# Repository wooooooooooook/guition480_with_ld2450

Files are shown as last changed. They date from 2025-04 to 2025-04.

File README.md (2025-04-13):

# guition480_with_ld2450
guition 4'' display ESP32-S3-4848S040 with LD2450 sensor

### 재료
- guition 4'' display ESP32-S3-4848S040 (3 relay 모델 기준 https://ko.aliexpress.com/item/1005006335587633.html) 
- LD2450 sensor (https://ko.aliexpress.com/item/1005007198006311.html)
- MX 1.25 4pin cable (https://ko.aliexpress.com/item/1005007277110532.html) : guition display에 연결
- ZH 1.5 4pin cable (https://ko.aliexpress.com/item/1005007277030322.html) : LD2450에 연결
- M4 둥근머리 볼트 25mm (더 길어도 관계없음. 스위치 고정에 쓰이는 볼트(이도피스) 재활용가능)
- [3D 프린팅 파츠](https://github.com/wooooooooooook/guition480_with_ld2450/tree/main/printing%20parts)

### 하드웨어


우측 상단에 1.25mm 4pin UART 포트가 존재함.
백패널과 연결포트에도 UART포트가 들어가는데 우측상단의 UART와 UART0핀을 공유하고있음 (GPIO 44, 43) 
백패널로 가는 uart는 저항이 없고, uart포트는 100옴 저항이 달려있음. 



100옴 저함 2개를 인두기로 제거후 납을묻혀 연결시켜야함.



백패널의 Rx, Tx는 아무데도 연결되지 않은것으로보임.
따라서 4pin UART포트를 사용 가능함.



포트 노출을 위해 뒷판을 잘라내야함. (사진 보다 깊게 잘라야 간섭이 없음)

### 어댑터 3D 프린터 출력


[프린팅파츠](https://github.com/wooooooooooook/guition480_with_ld2450/tree/main/printing%20parts)
프린팅 파츠에서 `cover.stl`, `plate.stl`을 출력.
- `plate_v2.stl`은 디스플레이 제거를 쉽게하기위해 하단 지지대를 뚫어놓은 버전입니다. 필요시 이 버전으로 사용하세요. 실제 출력 테스트는 안해봤습니다.

### ESPHome 펌웨어 설치
벽면에 설치후에는 usb포트노출이 안되므로 최초 1회는 USB-C 연결해서 유선으로 펌웨어설치가 필요함.
이후에는 OTA로 업데이트가능. 
[configuration.yaml](https://github.com/wooooooooooook/guition480_with_ld2450/blob/main/esphome%20configuration/guition.yaml)
YAML을 참조하여 ESPHome 펌웨어 설치.

### 설치하기


벽면에 사진과 같이 plate에 LD2450를 장착하고(그냥 걸쳐져있는 방식) 케이블을 잘 정리해서 볼트로 고정시킨다.
케이블의 경우 MX1.25와 ZH1.5케이블을 5V->5V, Rx->Tx, Tx->Rx, Gnd->Gnd가 되도록 연결했음. 



주의해서 L, N, L1~3을 연결하고 LD2450케이블은 위쪽으로 위치시켜서 디스플레이를 장착한다.



M4 볼트로 고정된 모습. (3D 프린팅에 나사를 밀어넣는 방식이므로 너무 세게 조이면 안됩니다.)



LD2450케이블을 본체에 연결한뒤 결합하면 완성





### 철거하기
- 커버 아래의 1자 틈에 1자드라이버를 넣고 비틀어 커버를 분리.
- 디스플레이의 좌우를 잡고 잘 뜯기.. ( 하단의 고정 홈을 누를 도구가 있다면 누르면서 뽑기)
- 이후 보이는 볼트를 제거하면서 탈거할 수 있음.

### 펌웨어 기본 기능
- Light 1~3은 후면 L1~3의 릴레이를 작동시킴
- Switch 1~3은 HA에서 자동화를통해 연동시켜 사용
- LD2450을 활용해 접근시 (2m이내) 화면이 켜짐. (딜레이가 있어 답답할 수도 있습니다)
- [Guition](https://devices.esphome.io/devices/Guition-ESP32-S3-4848S040) 공식문서의 아날로그시계, 날짜, IP주소 표시기능은 유지
- 우측하단의 Radar모양 버튼 클릭시 실시간 레이더 화면

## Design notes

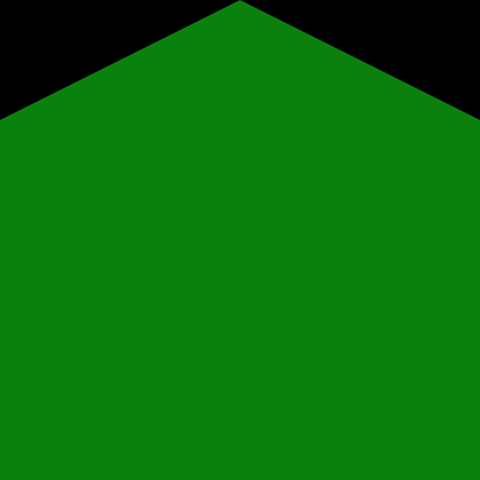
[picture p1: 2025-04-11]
esphome configuration/radar_background.png

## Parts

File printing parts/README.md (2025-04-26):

CAD viewer [Onshape CAD link](https://cad.onshape.com/documents/9057c41d81a8f1ddb4ad9576/w/45d8406c476935491145e5af/e/2f8b95da7adce26008260f7f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)

Onshape 회원가입시 export 가능.

## 파일 설명
- `plate.stl`: 고정용 플레이트. 첫번째 버전, 디스플레이 분리가 어렵습니다.
- `cover.stl`: 커버
- `plate_v2`: 디스플레이 분리를 위한 하단 홈을 뚤었음
- `plate_v3`: 하단홈 위치 맞추기 및 출렁거림 완화를 위한 구조 변경
- `plate_v4`: 지지대 추가, EU나사 홀 좀더 타이트하게
- `plate_only_without_LD2450.stl`: LD2450 없이 어댑터 플레이트만 필요한 경우 사용.
- `plate_only_without_LD2450.stl_v2`: `plate_v4`적용사항 적용함.

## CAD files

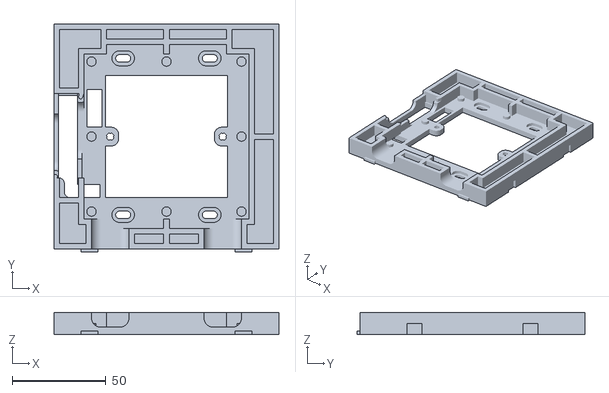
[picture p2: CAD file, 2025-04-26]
printing parts/plate_v4.stl
120.0 x 121.5 x 12.0

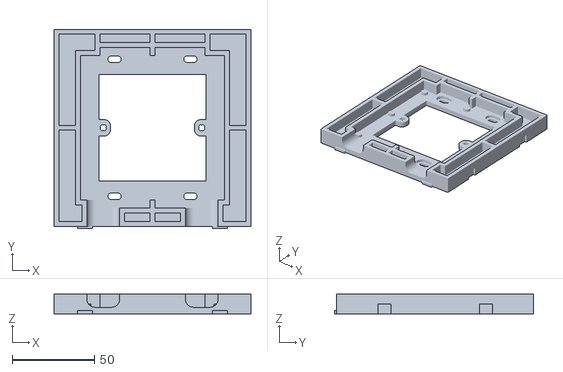
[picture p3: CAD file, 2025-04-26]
printing parts/plate_only_without_LD2450_v2.stl
120.0 x 121.5 x 12.0

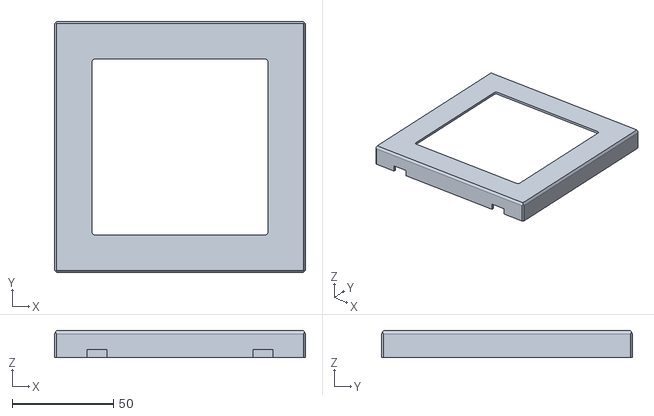
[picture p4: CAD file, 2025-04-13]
printing parts/cover.stl
124.2 x 124.2 x 13.5

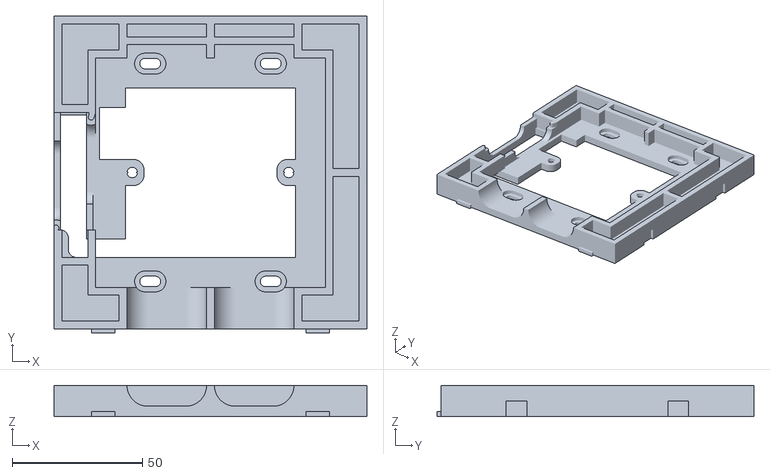
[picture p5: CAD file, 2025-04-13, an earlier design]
printing parts/plate_v2.stl
120.0 x 121.5 x 12.0

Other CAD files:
printing parts/plate_only_without_LD2450.stl
printing parts/plate_v3.stl
printing parts/plate.stl

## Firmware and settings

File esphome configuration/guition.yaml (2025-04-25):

## 이 구성에 사용되는 secrets는 다음과 같습니다.
## !secret encryption_key
## !secret ota_password
## !secret wifi_ssid
## !secret wifi_password
## !secret fallback_password

substitutions:
  name: "guition-esp32-s3-4848s040"
  friendly_name: "Guition480-basic"
  wifi_fallback_ssid: "Guitionv1 Fallback Hotspot"
  device_description: "Guition ESP32-S3-4848S040 480*480 Smart Screen"

# 디스플레이에 표시될 이름과 아이콘
  light_1_display_name: "Light1"
  light_1_icon: $mdi_lightbulb
  light_2_display_name: "Light2"
  light_2_icon: $mdi_lightbulb
  light_3_display_name: "Light3"
  light_3_icon: $mdi_lightbulb
  custom_switch_1_display_name: "Switch1"
  custom_switch_1_icon: $mdi_lamp
  custom_switch_2_display_name: "Switch2"
  custom_switch_2_icon: $mdi_lamp
  custom_switch_3_display_name: "Switch3"
  custom_switch_3_icon: $mdi_lamp

# 사용할 아이콘을 아래와 font: 섹션에 각각 추가하세요요
# mdi icons http://materialdesignicons.com/cdn/7.4.47/
  mdi_lightbulb: "\U000F0335"
  mdi_radar: "\U000F0437"
  mdi_chevron_double_left: "\U000F013D"
  mdi_lamp: "\U000F06B5"
  mdi_curtains: "\U000F1846"

# web_server:
#   port: 80
#   version: 3

color:
  # Create a Home Assistant blue color
  - id: ha_blue
    hex: 51c0f2

#-------------------------------------------
# Fonts
#-------------------------------------------
font:
  - file: "gfonts://Roboto"
    id: roboto24
    size: 24
    bpp: 4

  - file: "fonts/materialdesignicons-webfont.ttf" # http://materialdesignicons.com/cdn/7.4.47/
    id: light40
    size: 40
    bpp: 4
    glyphs: [
        "\U000F0335", # mdi_mdi_lightbulb
        "\U000F0437", # mdi_radar
        "\U000F013D", # mdi_chevron_double_left
        "\U000F06B5", # mdi_lamp
        "\U000F1846", # mid_curtains
      ]
      
esphome:
  name: "${name}"
  friendly_name: "${friendly_name}"
  #name_add_mac_suffix: true
  platformio_options:
    board_build.flash_mode: dio
  on_boot:
    priority: 600
    then:
      - lvgl.widget.hide:
          - id: target1_obj
      - lvgl.widget.hide:
          - id: target2_obj
      - lvgl.widget.hide:
          - id: target3_obj

esp32:
  board: esp32-s3-devkitc-1
  variant: esp32s3
  flash_size: 16MB
  framework:
    type: esp-idf
    sdkconfig_options:
      COMPILER_OPTIMIZATION_SIZE: y
      CONFIG_ESP32S3_DEFAULT_CPU_FREQ_240: "y"
      CONFIG_ESP32S3_DATA_CACHE_64KB: "y"
      CONFIG_ESP32S3_DATA_CACHE_LINE_64B: "y"
      CONFIG_SPIRAM_FETCH_INSTRUCTIONS: y
      CONFIG_SPIRAM_RODATA: y

## 블루투스스와 LD2450는 성능상 동시에 사용이 불가. 동시에 활성화할경우 OTA접속이 불가해질 수 있으니 주의.
# esp32_ble_tracker:
#   scan_parameters:
#     window: 30ms
#     interval: 100ms
# bluetooth_proxy:

psram:
  mode: octal
  speed: 80MHz

# Enable logging
logger:
  baud_rate: 0 # 하드웨어 로거가 사용할 UART없음. 충돌방지 위해 비활성화.

# Enable Home Assistant API
api:
  encryption:
    key: !secret encryption_key

ota:
  - platform: esphome
    id: my_ota
    password: !secret ota_password

wifi:
  ssid: !secret wifi_ssid
  password: !secret wifi_password
  fast_connect: True

  # Enable fallback hotspot (captive portal) in case wifi connection fails
  ap:
    ssid: "${wifi_fallback_ssid}"
    password: !secret fallback_password


time:
  - platform: homeassistant
    id: time_comp
    on_time_sync:
      - script.execute: time_update
    on_time:
      - minutes: '*'
        seconds: 0
        then:
          - script.execute: time_update
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

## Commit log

2025-04-10 README.md 파일 업데이트: 내용 수정 및 정보 추가
    [cover.stl, plate.stl]
2025-04-22 printing parts 추가가
    [plate_only_without_LD2450.stl, plate_v3.stl]
